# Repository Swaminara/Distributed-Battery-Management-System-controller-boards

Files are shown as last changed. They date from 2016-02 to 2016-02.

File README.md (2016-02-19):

# Distributed-Battery-Management-System-controller-boards

This repository contains the hardware design files of the cell-level controller boards of a distributed Battery Management System.

The boards are designed using Easily Applicable Graphical Layout Editor (EAGLE) 7.1.0 for Windows. However, they can be viewed and edited using other versions also. 

A journal paper explaining the individual modules of the cell-level controller is under review and will be soon updated to this repository. 

This repository is protected under the MIT license as attached in the repository.

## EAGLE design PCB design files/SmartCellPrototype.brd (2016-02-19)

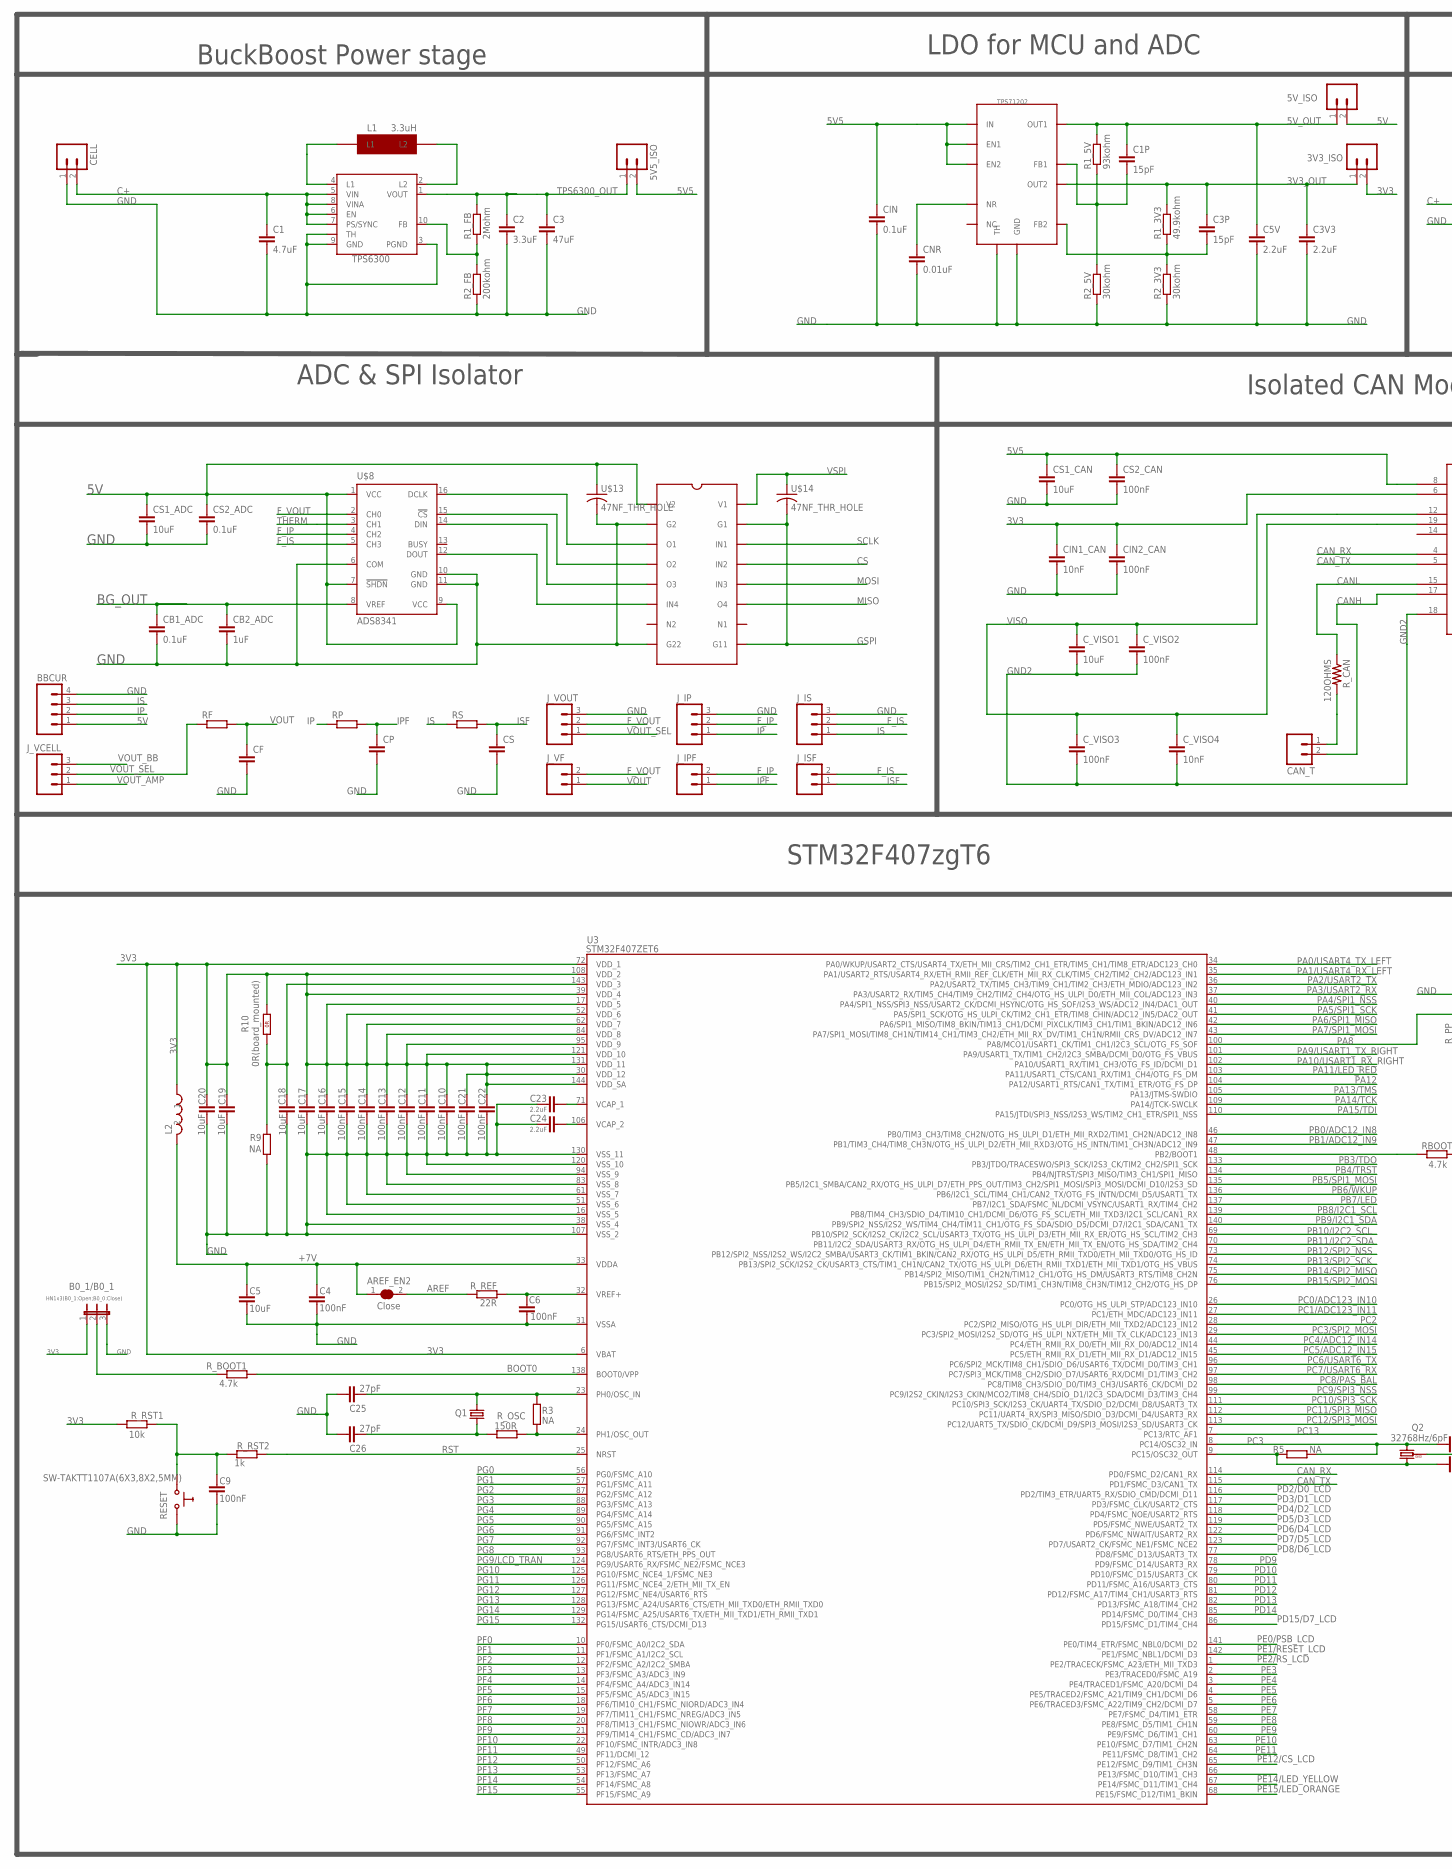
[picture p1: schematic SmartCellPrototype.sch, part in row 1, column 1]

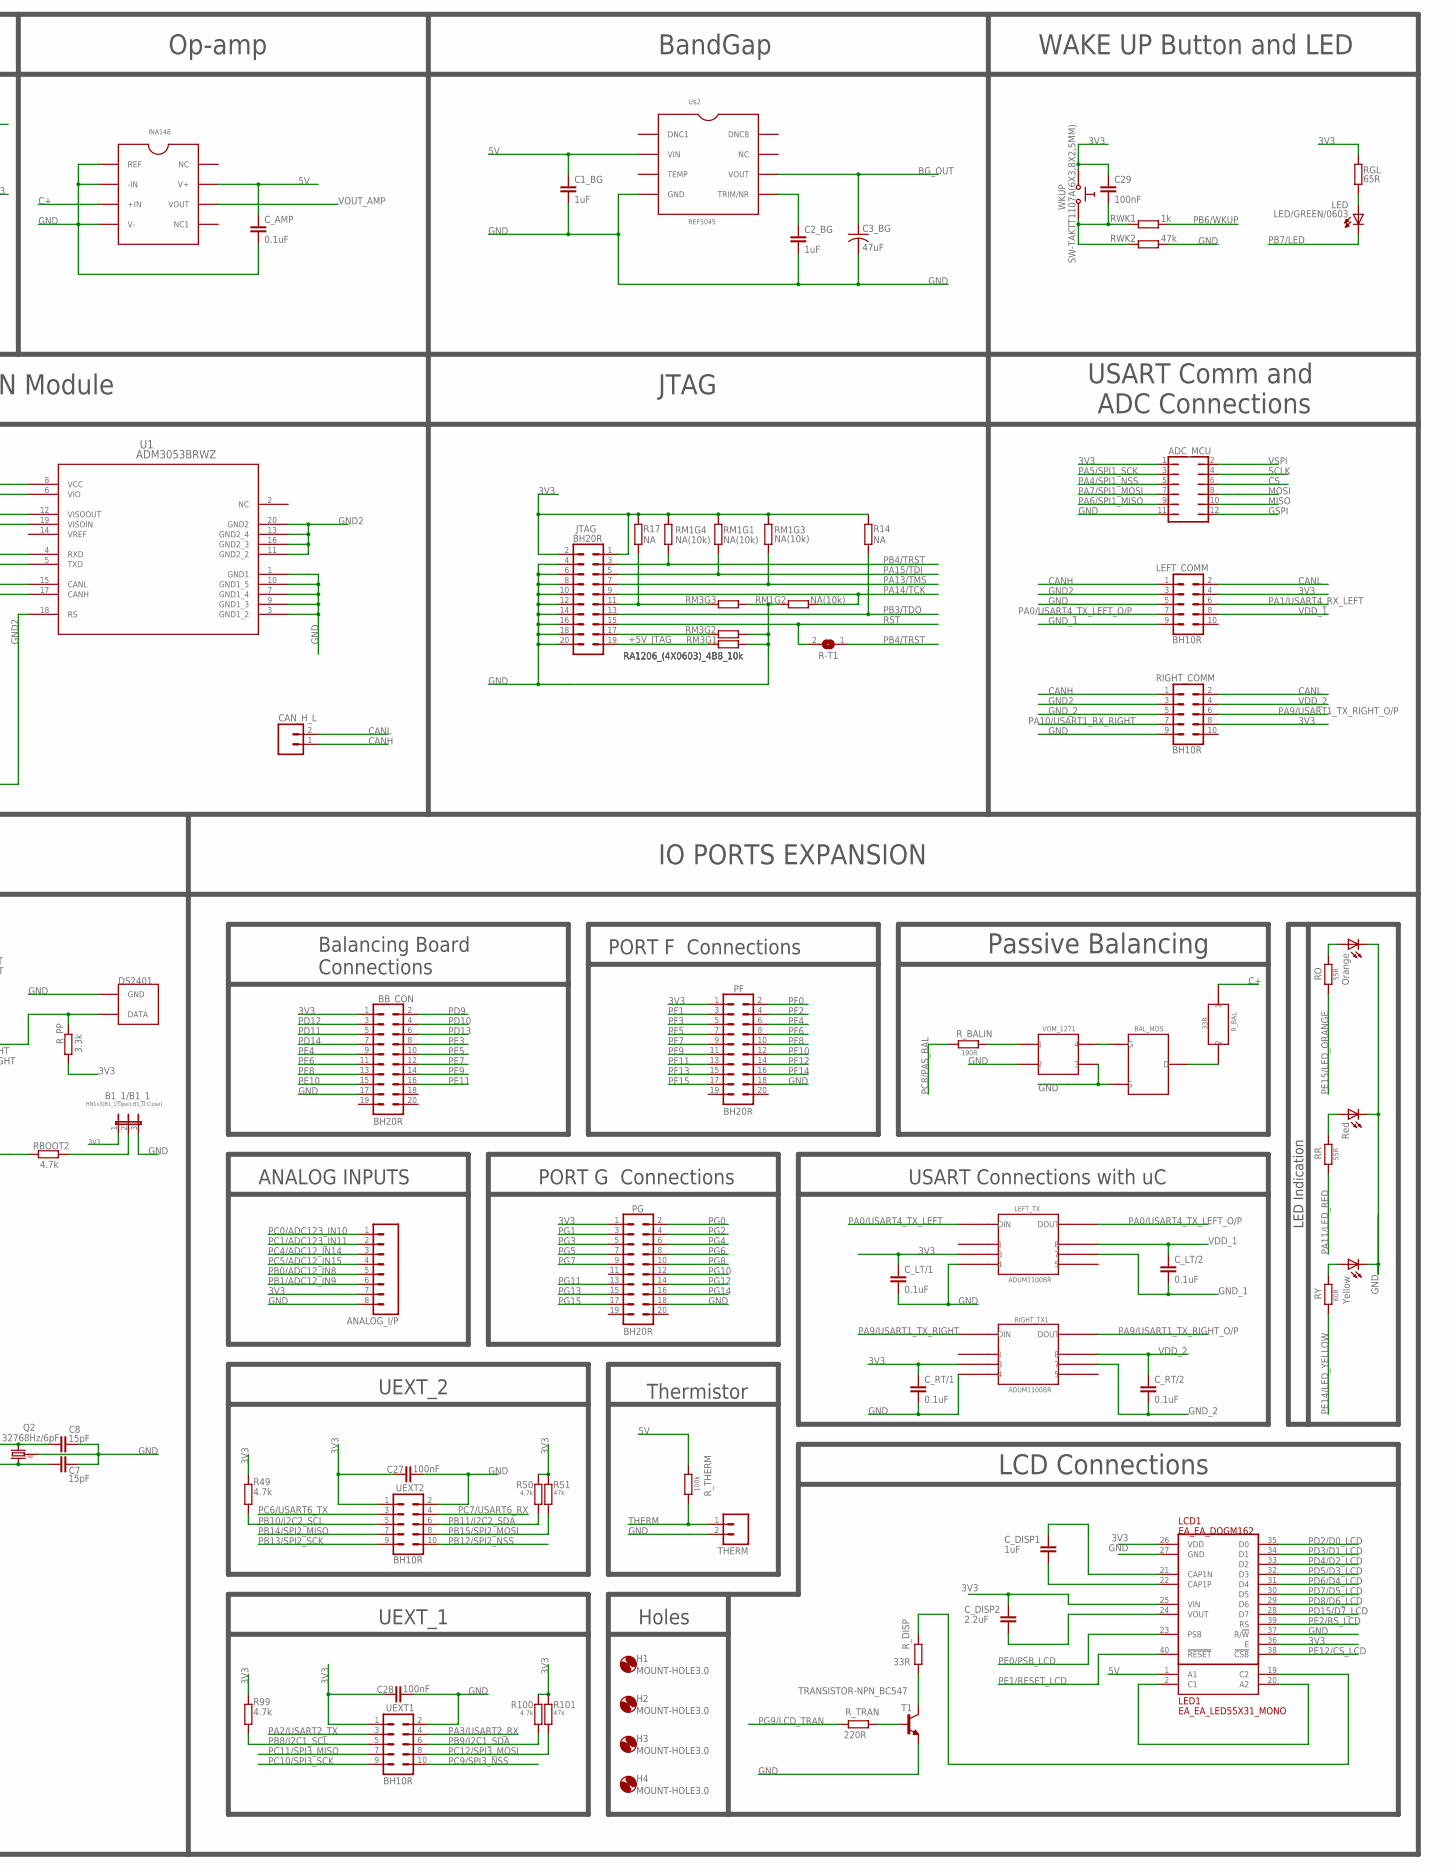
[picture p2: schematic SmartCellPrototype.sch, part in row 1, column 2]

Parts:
3V3_ISO, 5V5_ISO, 5V_ISO: M02PTH; 1X02
ADC_MCU: JP6Q
ANALOG_I/P: M081X08; 1X08
AREF_EN2: Close; SJ_1_SMALLER_CLOSE
B0_1/B0_1: HN1x3(B0_1:Open;B0_0:Close); JP2
B1_1/B1_1: HN1x3(B1_1:Open;B1_0:Close); JP2
BAL_MOS: BAL_MOS
BBCUR: M04PTH; 1X04
BB_CON: BH20R
C1: 4.7uF; C0603
C1P, C3P, C7, C8: 15pF; C0603
C1_BG, C2_BG: 1uF; C0603
C2: 3.3uF; C0603
C3: 47uF; C0805
C3V3, C5V, C23, C24: 2.2uF; C0603
C3_BG: 47uF; C3_BG
C4, C6, C9, C10, C11, C12, C13, C14, C15, C21, C22, C27, C28: 100nF; C0603
C5, C16, C17, C18, C19, C20: 10uF; C0603
C25, C26: 27pF; C0603
C29: 100nF; C0805
CAN_H_L: M02PTH; 1X02
CAN_T: M02PTH; 1X02
CB1_ADC: 0.1uF; C0603
CB2_ADC: 1uF; C0603
CELL: M023.5MM; SCREWTERMINAL-3.5MM-2
CF: C-EUC0603; C0603
CIN: 0.1uF; C0603
CIN1_CAN: 10nF; C0603
CIN2_CAN: 100nF; C0603
CNR: 0.01uF; C0603
CP: C-EUC0603; C0603
CS: C-EUC0603; C0603
CS1_ADC, CS1_CAN: 10uF; C0603
CS2_ADC: 0.1uF; C0603
CS2_CAN: 100nF; C0603
C_AMP: 0.1uF; C0603
C_DISP1: 1uF; C0603
C_DISP2: 2.2uF; C0603
C_LT/1, C_LT/2: 0.1uF; C0603
C_RT/1, C_RT/2: 0.1uF; C0603
C_VISO1: 10uF; C0603
C_VISO2, C_VISO3: 100nF; C0603
C_VISO4: 10nF; C0603
DS2401: DS2401
H1, H2, H3, H4: MOUNT-HOLE3.0; 3,0
HCPL092J-00E: HCPL902
IC1: TPS6300; DRC-S-PVSON-N10
INA148: INA148
JTAG: BH20R
J_IP: M03PTH; 1X03
J_IPF: M02PTH; 1X02
J_IS: M03PTH; 1X03
J_ISF: M02PTH; 1X02
J_VCELL: M03PTH; 1X03
J_VF: M02PTH; 1X02
J_VOUT: M03PTH; 1X03
L1: 3.3uH; IND_COILCRAFT3.3UH
L2: FERRITE_BEAD
LCD1: EA_EA_DOGM162; EA_EA_DOGM
LED: LED/GREEN/0603; LED-0603
LED1: EA_EA_LED55X31_MONO; EA_EA_LED55X31
LEFT_COMM: BH10R
LEFT_TX: ADUM1100BR; R_8
PF: BH20R
PG: BH20R
Q1: HC49/S2; HC49/SMD2
Q2: 32768Hz/6pF; TC26H_3_REPAIR_SMD
R1_3V3: 49.9kohm; R0603
R1_5V: 93kohm; R0603
R1_FB: 2Mohm; R0603
R2_3V3, R2_5V: 30kohm; R0603
R2_FB: 200kohm; R0603
R3, R5, R9, R14, R17: NA; R0603
R10: 0R(board_mounted); 0603_0R
R49, R50, R99, R100: 4.7k; R0603
R51, R101: 47k; R0603
R-T1: Open; SJ_1_SMALLER
RBOOT2: 4.7k; R0603
RESET: SW-TAKTT1107A(6X3,8X2,5MM); WS-TAKT_6X3.5_SMD_NOCREAM
RF: R-EU_R0603; R0603
RGL: 65R; R0603_5MIL_DWS
RIGHT_COMM: BH10R
RIGHT_TX1: ADUM1100BR; R_8
RM1: NA(10k); R_MATRIX_4
RM3: RA1206_(4X0603)_4B8_10k; R_MATRIX_4
RO: 55R; R0603
RP: R-EU_R0603; R0603
RR: 55R; R0603
RS: R-EU_R0603; R0603
RWK1: 1k; R0603_5MIL_DWS
RWK2: 47k; R0603_5MIL_DWS
RY: 60R; R0603
R_BAL: 33R; R_BAL
R_BALIN: 190R; R0603
R_BOOT1: 4.7k; R0603
R_CAN: 120OHMS; 120OHM
R_DISP: 33R; R0603
R_OSC: 150R; R0603
R_PP: 3.3k; R0603
R_REF: 22R; R0603
R_RST1: 10k; R0603
R_RST2: 1k; R0603
R_THERM: 100k; R0603
R_TRAN: 220R; R0603
T1: TRANSISTOR-NPN_BC547; TRANSISTOR-NPN_TO92
THERM: M02JST-PTH-2; JST-2-PTH
U1: ADM3053BRWZ; RW_20
U3: STM32F407ZET6; LQFP144
U$1: TPS71202; TPS71202_LDO_ADC_MCU
U$2: REF5045; REF5045_BG
U$3: Yellow; LED_0805
U$4: Red; LED_0805
U$5: Orange; LED_0805
U$8: ADS8341
U$13, U$14: 47NF_THR_HOLE
UEXT1, UEXT2: BH10R
VOM_1271: VOM1271
WKUP: SW-TAKTT1107A(6X3,8X2,5MM); WS-TAKT_6X3.5_SMD_NOCREAM

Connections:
3V3: 3V3_ISO.2, ADC_MCU.1, ANALOG_I/P.7, B0_1/B0_1.1, B1_1/B1_1.1, BB_CON.1, C10.2, C11.2, C12.2, C13.2, C14.2, C15.2, C16.2, C17.2, C19.2, C20.2, C21.2, C22.2, C27.2, C28.2, C29.2, CIN1_CAN.1, CIN2_CAN.1, C_DISP2.1, C_LT/1.1, C_RT/1.1, JTAG.1, JTAG.2, L2.1, LCD1.25 (VIN), LCD1.26 (VDD), LCD1.36 (E), LEFT_COMM.4, LEFT_TX.3, PF.1, PG.1, R10.2 (1.2), R14.2, R17.2, R49.2, R50.2, R51.2, R99.2, R100.2, R101.2, RGL.2, RIGHT_COMM.8, RIGHT_TX1.3, RM1.1.2 (2), RM1.3.2 (2), RM1.4.2 (2), R_PP.1, R_RST1.2, U1.6 (VIO), U3.6 (VBAT), U3.17 (VDD_5), U3.30 (VDD_12), U3.39 (VDD_4), U3.52 (VDD_6), U3.62 (VDD_7), U3.72 (VDD_1), U3.84 (VDD_8), U3.95 (VDD_9), U3.108 (VDD_2), U3.121 (VDD_10), U3.131 (VDD_11), U3.144 (VDD_SA), UEXT1.1, UEXT2.1, WKUP.P$1 (0)
3V3_OUT: 3V3_ISO.1, C3P.1, C3V3.1, R1_3V3.2, U$1.4 (OUT2)
5V: 5V_ISO.2, BBCUR.1, C1_BG.1, CS1_ADC.1, CS2_ADC.1, C_AMP.1, HCPL092J-00E.V2, INA148.V+, LED1.1 (A1), R_THERM.2, U$2.VIN, U$8.1 (VCC), U$8.7 (!SHDN), U$8.9 (VCC), U$13.1
5V5: 5V5_ISO.2, CIN.1, CS1_CAN.1, CS2_CAN.1, U1.8 (VCC), U$1.1 (IN), U$1.8 (EN2), U$1.10 (EN1)
5V_OUT: 5V_ISO.1, C1P.1, C5V.1, R1_5V.2, U$1.3 (OUT1)
+5V_JTAG: JTAG.19, RM3.1.1 (1)
+7V: AREF_EN2.1, C4.2, C5.1, L2.2, U3.33 (VDDA)
AREF: AREF_EN2.2, R_REF.1
BG_OUT: C3_BG.+, CB1_ADC.1, CB2_ADC.1, U$2.VOUT, U$8.8 (VREF)
BOOT0: R_BOOT1.1, U3.138 (BOOT0/VPP)
C+: C1.1, CELL.2, IC1.5 (VIN), IC1.6 (EN), IC1.7 (PS/SYNC), IC1.8 (VINA), INA148.+IN, R_BAL.1
CANH: CAN_H_L.1, CAN_T.2, LEFT_COMM.1, RIGHT_COMM.1, U1.17 (CANH)
CANL: CAN_H_L.2, LEFT_COMM.2, RIGHT_COMM.2, R_CAN.1, U1.15 (CANL)
CAN_RX: U1.4 (RXD), U3.114 (PD0/FSMC_D2/CAN1_RX)
CAN_TX: U1.5 (TXD), U3.115 (PD1/FSMC_D3/CAN1_TX)
CS: ADC_MCU.6, HCPL092J-00E.IN2
F_IP: J_IP.2, J_IPF.2, U$8.4 (CH2)
F_IS: J_IS.2, J_ISF.2, U$8.5 (CH3)
F_VOUT: J_VF.2, J_VOUT.2, U$8.2 (CH0)
GND: ADC_MCU.11, ANALOG_I/P.8, B0_1/B0_1.3, B1_1/B1_1.3, BAL_MOS.S, BBCUR.4, BB_CON.17, C1.2, C1_BG.2, C2.2, C2_BG.2, C3.2, C3V3.2, C3_BG.-, C4.1, C5.2, C5V.2, C6.1, C7.2, C8.2, C9.1, C10.1, C11.1, C12.1, C13.1, C14.1, C15.1, C16.1, C17.1, C18.1, C19.1, C20.1, C21.1, C22.1, C23.1, C24.1, C25.2, C26.2, C27.1, C28.1, CB1_ADC.2, CB2_ADC.2, CELL.1, CF.2, CIN.2, CIN1_CAN.2, CIN2_CAN.2, CNR.2, CP.2, CS.2, CS1_ADC.2, CS1_CAN.2, CS2_ADC.2, CS2_CAN.2, C_AMP.2, C_LT/1.2, C_RT/1.2, DS2401.GND, HCPL092J-00E.G2, HCPL092J-00E.G22, IC1.3 (PGND), IC1.9 (GND), IC1.TH, INA148.-IN, INA148.REF, INA148.V-, JTAG.4, JTAG.6, JTAG.8, JTAG.10, JTAG.12, JTAG.14, JTAG.16, JTAG.18, JTAG.20, J_IP.3, J_IS.3, J_VOUT.3, LCD1.27 (GND), LCD1.37 (R/!W!), LEFT_COMM.5, LEFT_TX.4, PF.18, PG.18, Q2.GND, R2_3V3.1, R2_5V.1, R2_FB.1, R9.2, RESET.P$2 (1), RIGHT_COMM.9, RIGHT_TX1.4, RM1.2.1 (1), RM3.1.2 (2), RM3.2.2 (2), RM3.3.2 (2), RWK2.1, T1.1 (E), THERM.2, U1.1 (GND1), U1.3 (GND1_2), U1.7 (GND1_4), U1.9 (GND1_3), U1.10 (GND1_5), U3.16 (VSS_5), U3.31 (VSSA), U3.38 (VSS_4), U3.51 (VSS_6), U3.61 (VSS_7), U3.83 (VSS_8), U3.94 (VSS_9), U3.107 (VSS_2), U3.120 (VSS_10), U3.130 (VSS_11), U$1.5 (GND), U$1.TH, U$2.GND, U$3.K (C), U$4.K (C), U$5.K (C), U$8.6 (COM), U$8.10 (GND), U$8.11 (GND), U$13.2, UEXT1.2, UEXT2.2, VOM_1271.2, VOM_1271.3
GND2: C_VISO1.2, C_VISO2.2, C_VISO3.2, C_VISO4.2, LEFT_COMM.3, RIGHT_COMM.3, U1.11 (GND2_2), U1.13 (GND2_4), U1.16 (GND2_3), U1.18 (RS), U1.20 (GND2)
GND_1: C_LT/2.2, LEFT_COMM.9, LEFT_TX.7
GND_2: C_RT/2.2, RIGHT_COMM.5, RIGHT_TX1.7
GSPI: ADC_MCU.12, HCPL092J-00E.G1, HCPL092J-00E.G11, U$14.2
IP: BBCUR.2, J_IP.1, RP.1
IPF: CP.1, J_IPF.1, RP.2
IS: BBCUR.3, J_IS.1, RS.1
ISF: CS.1, J_ISF.1, RS.2
MISO: ADC_MCU.10, HCPL092J-00E.OUT4 (O4)
MOSI: ADC_MCU.8, HCPL092J-00E.IN3
unnamed: IC1.4 (L1), L1.L1
unnamed: IC1.2 (L2), L1.L2
unnamed: CAN_T.1, R_CAN.2
unnamed: C25.1, Q1.1, R3.2, U3.23 (PH0/OSC_IN)
unnamed: IC1.10 (FB), R1_FB.1, R2_FB.2
unnamed: CNR.1, U$1.6 (NR)
unnamed: C3P.2, R1_3V3.1, R2_3V3.2, U$1.7 (FB2)
unnamed: R3.1, R_OSC.2, U3.24 (PH1/OSC_OUT)
unnamed: C2_BG.1, U$2.TRIM/NR
unnamed: C1P.2, R1_5V.1, R2_5V.2, U$1.9 (FB1)
unnamed: B0_1/B0_1.2, R_BOOT1.2
unnamed: C9.2, RESET.P$1 (0), R_RST1.1, R_RST2.2
unnamed: LED.A, RGL.1
unnamed: C26.1, Q1.2, R_OSC.1
unnamed: BAL_MOS.D, R_BAL.2
unnamed: BAL_MOS.G, VOM_1271.4
unnamed: C23.2, U3.71 (VCAP_1)
unnamed: RY.1, U$3.A
unnamed: HCPL092J-00E.IN4, U$8.12 (DOUT)
unnamed: HCPL092J-00E.OUT3 (O3), U$8.14 (DIN)
unnamed: HCPL092J-00E.OUT2 (O2), U$8.15 (!CS)
unnamed: HCPL092J-00E.OUT1 (O1), U$8.16 (DCLK)
unnamed: C_DISP1.1, LCD1.21 (CAP1N)
unnamed: C29.1, RWK1.1, RWK2.2, WKUP.P$2 (1)
unnamed: RR.1, U$4.A
unnamed: RBOOT2.1, U3.48 (PB2/BOOT1)
unnamed: RO.1, U$5.A
unnamed: C24.2, U3.106 (VCAP_2)
unnamed: C_DISP1.2, LCD1.22 (CAP1P)
unnamed: R_BALIN.2, VOM_1271.1
unnamed: C_DISP2.2, LCD1.24 (VOUT)
unnamed: LED1.2 (C1), LED1.20 (A2)
unnamed: C18.2, R9.1, R10.1 (1.1), U3.143 (VDD_3)
unnamed: B1_1/B1_1.2, RBOOT2.2
unnamed: JTAG.11, R17.1, RM3.3.1 (1)
unnamed: JTAG.17, RM3.2.1 (1)
unnamed: LED1.19 (C2), R_DISP.2
unnamed: R_DISP.1, T1.3 (C)
unnamed: R_TRAN.1, T1.2 (B)
PA0/USART4_TX_LEFT: LEFT_TX.2 (DIN), U3.34 (PA0/WKUP/USART2_CTS/USART4_TX/ETH_MII_C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)
PA0/USART4_TX_LEFT_O/P: LEFT_COMM.7, LEFT_TX.6 (DOUT)
PA1/USART4_RX_LEFT: LEFT_COMM.6, U3.35 (PA1/USART2_RTS/USART4_RX/ETH_RMII_REF_C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)
PA2/USART2_TX: U3.36 (PA2/USART2_TX/TIM5_CH3/TIM9_CH1/TIM2_CH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), UEXT1.3
PA3/USART2_RX: U3.37 (PA3/USART2_RX/TIM5_CH4/TIM9_CH2/TIM2_CH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), UEXT1.4
PA4/SPI1_NSS: ADC_MCU.5, U3.40 (PA4/SPI1_NSS/SPI3_NSS/USART2_CK/DCMI_HS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)
PA5/SPI1_SCK: ADC_MCU.3, U3.41 (PA5/SPI1_SCK/OTG_HS_ULPI_CK/TIM2_CH1_ET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)
PA6/SPI1_MISO: ADC_MCU.9, U3.42 (PA6/SPI1_MISO/TIM8_BKIN/TIM13_CH1/DCMI_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)
PA7/SPI1_MOSI: ADC_MCU.7, U3.43 (PA7/SPI1_MOSI/TIM8_CH1N/TIM14_CH1/TIM3_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)
PA8: DS2401.DATA, R_PP.2, U3.100 (PA8/MCO1/USART1_CK/TIM1_CH1/I2C3_SCL/OT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)
PA9/USART1_TX_RIGHT: RIGHT_TX1.2 (DIN), U3.101 (PA9/USART1_TX/TIM1_CH2/I2C3_SMBA/DCMI_D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)
PA9/USART1_TX_RIGHT_O/P: RIGHT_COMM.6, RIGHT_TX1.6 (DOUT)
PA10/USART1_RX_RIGHT: RIGHT_COMM.7, U3.102 (PA10/USART1_RX/TIM1_CH3/OTG_FS_ID/DCMI_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)
PA11/LED_RED: RR.2, U3.103 (PA11/USART1_CTS/CAN1_RX/TIM1_CH4/OTG_FS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)
PA12: U3.104 (PA12/USART1_RTS/CAN1_TX/TIM1_ETR/OTG_FS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)
PA13/TMS: JTAG.7, RM1.3.1 (1), U3.105 (PA13/JTMS-SWDIO)
PA14/TCK: JTAG.9, RM1.2.2 (2), U3.109 (PA14/JTCK-SWCLK)
PA15/TDI: JTAG.5, RM1.1.1 (1), U3.110 (PA15/JTDI/SPI3_NSS/I2S3_WS/TIM2_CH1_ETR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)
PB0/ADC12_IN8: ANALOG_I/P.5, U3.46 (PB0/TIM3_CH3/TIM8_CH2N/OTG_HS_ULPI_D1/E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)
PB1/ADC12_IN9: ANALOG_I/P.6, U3.47 (PB1/TIM3_CH4/TIM8_CH3N/OTG_HS_ULPI_D2/E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)
PB3/TDO: JTAG.13, R14.1, U3.133 (PB3/JTDO/TRACESWO/SPI3_SCK/I2S3_CK/TIM2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)
PB4/TRST: JTAG.3, R-T1.1, RM1.4.1 (1), U3.134 (PB4/NJTRST/SPI3_MISO/TIM3_CH1/SPI1_MISO)
PB5/SPI1_MOSI: U3.135 (PB5/I2C1_SMBA/CAN2_RX/OTG_HS_ULPI_D7/ET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)
PB6/WKUP: RWK1.2, U3.136 (PB6/I2C1_SCL/TIM4_CH1/CAN2_TX/OTG_FS_IN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)
PB7/LED: LED.C, U3.137 (PB7/I2C1_SDA/FSMC_NL/DCMI_VSYNC/USART1_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)
PB8/I2C1_SCL: R99.1, U3.139 (PB8/TIM4_CH3/SDIO_D4/TIM10_CH1/DCMI_D6/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), UEXT1.5
PB9/I2C1_SDA: R100.1, U3.140 (PB9/SPI2_NSS/I2S2_WS/TIM4_CH4/TIM11_CH1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), UEXT1.6
PB10/I2C2_SCL: R49.1, U3.69 (PB10/SPI2_SCK/I2S2_CK/I2C2_SCL/USART3_T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), UEXT2.5
PB11/I2C2_SDA: R50.1, U3.70 (PB11/I2C2_SDA/USART3_RX/OTG_HS_ULPI_D4/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), UEXT2.6
PB12/SPI2_NSS: U3.73 (PB12/SPI2_NSS/I2S2_WS/I2C2_SMBA/USART3_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), UEXT2.10
PB13/SPI2_SCK: U3.74 (PB13/SPI2_SCK/I2S2_CK/USART3_CTS/TIM1_C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), UEXT2.9
PB14/SPI2_MISO: U3.75 (PB14/SPI2_MISO/TIM1_CH2N/TIM12_CH1/OTG_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), UEXT2.7
PB15/SPI2_MOSI: R51.1, U3.76 (PB15/SPI2_MOSI/I2S2_SD/TIM1_CH3N/TIM8_C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), UEXT2.8
PC0/ADC123_IN10: ANALOG_I/P.1, U3.26 (PC0/OTG_HS_ULPI_STP/ADC123_IN10)
PC1/ADC123_IN11: ANALOG_I/P.2, U3.27 (PC1/ETH_MDC/ADC123_IN11)
PC2: U3.28 (PC2/SPI2_MISO/OTG_HS_ULPI_DIR/ETH_MII_T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)
PC3: C8.1, Q2.2, R5.2, U3.8 (PC14/OSC32_IN)
PC3/SPI2_MOSI: U3.29 (PC3/SPI2_MOSI/I2S2_SD/OTG_HS_ULPI_NXT/E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)
PC4: C7.1, Q2.1, R5.1, U3.9 (PC15/OSC32_OUT)
PC4/ADC12_IN14: ANALOG_I/P.3, U3.44 (PC4/ETH_RMII_RX_D0/ETH_MII_RX_D0/ADC12_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)
PC5/ADC12_IN15: ANALOG_I/P.4, U3.45 (PC5/ETH_RMII_RX_D1/ETH_MII_RX_D1/ADC12_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)
PC6/USART6_TX: U3.96 (PC6/SPI2_MCK/TIM8_CH1/SDIO_D6/USART6_TX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), UEXT2.3
PC7/USART6_RX: U3.97 (PC7/SPI3_MCK/TIM8_CH2/SDIO_D7/USART6_RX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), UEXT2.4
PC8/PAS_BAL: R_BALIN.1, U3.98 (PC8/TIM8_CH3/SDIO_D0/TIM3_CH3/USART6_CK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)
PC9/SPI3_NSS: U3.99 (PC9/I2S2_CKIN/I2S3_CKIN/MCO2/TIM8_CH4/S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), UEXT1.10
PC10/SPI3_SCK: U3.111 (PC10/SPI3_SCK/I2S3_CK/UART4_TX/SDIO_D2/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), UEXT1.9
PC11/SPI3_MISO: U3.112 (PC11/UART4_RX/SPI3_MISO/SDIO_D3/DCMI_D4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), UEXT1.7
PC12/SPI3_MOSI: R101.1, U3.113 (PC12/UART5_TX/SDIO_CK/DCMI_D9/SPI3_MOSI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), UEXT1.8
PC13: U3.7 (PC13/RTC_AF1)
PD2/D0_LCD: LCD1.35 (D0), U3.116 (PD2/TIM3_ETR/UART5_RX/SDIO_CMD/DCMI_D11)
PD3/D1_LCD: LCD1.34 (D1), U3.117 (PD3/FSMC_CLK/USART2_CTS)
PD4/D2_LCD: LCD1.33 (D2), U3.118 (PD4/FSMC_NOE/USART2_RTS)
PD5/D3_LCD: LCD1.32 (D3), U3.119 (PD5/FSMC_NWE/USART2_TX)
PD6/D4_LCD: LCD1.31 (D4), U3.122 (PD6/FSMC_NWAIT/USART2_RX)
PD7/D5_LCD: LCD1.30 (D5), U3.123 (PD7/USART2_CK/FSMC_NE1/FSMC_NCE2)
PD8/D6_LCD: LCD1.29 (D6), U3.77 (PD8/FSMC_D13/USART3_TX)
PD9: BB_CON.2, U3.78 (PD9/FSMC_D14/USART3_RX)
PD10: BB_CON.4, U3.79 (PD10/FSMC_D15/USART3_CK)
PD11: BB_CON.5, U3.80 (PD11/FSMC_A16/USART3_CTS)
PD12: BB_CON.3, U3.81 (PD12/FSMC_A17/TIM4_CH1/USART3_RTS)
PD13: BB_CON.6, U3.82 (PD13/FSMC_A18/TIM4_CH2)
PD14: BB_CON.7, U3.85 (PD14/FSMC_D0/TIM4_CH3)
PD15/D7_LCD: LCD1.28 (D7), U3.86 (PD15/FSMC_D1/TIM4_CH4)
PE0/PSB_LCD: LCD1.23 (PSB), U3.141 (PE0/TIM4_ETR/FSMC_NBL0/DCMI_D2)
PE1/RESET_LCD: LCD1.40 (!RESET!), U3.142 (PE1/FSMC_NBL1/DCMI_D3)
PE2/RS_LCD: LCD1.39 (RS), U3.1 (PE2/TRACECK/FSMC_A23/ETH_MII_TXD3)
PE3: BB_CON.8, U3.2 (PE3/TRACED0/FSMC_A19)
PE4: BB_CON.9, U3.3 (PE4/TRACED1/FSMC_A20/DCMI_D4)
PE5: BB_CON.10, U3.4 (PE5/TRACED2/FSMC_A21/TIM9_CH1/DCMI_D6)
PE6: BB_CON.11, U3.5 (PE6/TRACED3/FSMC_A22/TIM9_CH2/DCMI_D7)
PE7: BB_CON.12, U3.58 (PE7/FSMC_D4/TIM1_ETR)
PE8: BB_CON.13, U3.59 (PE8/FSMC_D5/TIM1_CH1N)
PE9: BB_CON.14, U3.60 (PE9/FSMC_D6/TIM1_CH1)
PE10: BB_CON.15, U3.63 (PE10/FSMC_D7/TIM1_CH2N)
PE11: BB_CON.16, U3.64 (PE11/FSMC_D8/TIM1_CH2)
PE12/CS_LCD: LCD1.38 (!CSB!), U3.65 (PE12/FSMC_D9/TIM1_CH3N)
PE14/LED_YELLOW: RY.2, U3.67 (PE14/FSMC_D11/TIM1_CH4)
PE15/LED_ORANGE: RO.2, U3.68 (PE15/FSMC_D12/TIM1_BKIN)
PF0: PF.2, U3.10 (PF0/FSMC_A0/I2C2_SDA)
PF1: PF.3, U3.11 (PF1/FSMC_A1/I2C2_SCL)
PF2: PF.4, U3.12 (PF2/FSMC_A2/I2C2_SMBA)
PF3: PF.5, U3.13 (PF3/FSMC_A3/ADC3_IN9)
PF4: PF.6, U3.14 (PF4/FSMC_A4/ADC3_IN14)
PF5: PF.7, U3.15 (PF5/FSMC_A5/ADC3_IN15)
PF6: PF.8, U3.18 (PF6/TIM10_CH1/FSMC_NIORD/ADC3_IN4)
PF7: PF.9, U3.19 (PF7/TIM11_CH1/FSMC_NREG/ADC3_IN5)
PF8: PF.10, U3.20 (PF8/TIM13_CH1/FSMC_NIOWR/ADC3_IN6)
PF9: PF.11, U3.21 (PF9/TIM14_CH1/FSMC_CD/ADC3_IN7)
PF10: PF.12, U3.22 (PF10/FSMC_INTR/ADC3_IN8)
PF11: PF.13, U3.49 (PF11/DCMI_12)
PF12: PF.14, U3.50 (PF12/FSMC_A6)
PF13: PF.15, U3.53 (PF13/FSMC_A7)
PF14: PF.16, U3.54 (PF14/FSMC_A8)
PF15: PF.17, U3.55 (PF15/FSMC_A9)
PG0: PG.2, U3.56 (PG0/FSMC_A10)
PG1: PG.3, U3.57 (PG1/FSMC_A11)
PG2: PG.4, U3.87 (PG2/FSMC_A12)
PG3: PG.5, U3.88 (PG3/FSMC_A13)
PG4: PG.6, U3.89 (PG4/FSMC_A14)
PG5: PG.7, U3.90 (PG5/FSMC_A15)
PG6: PG.8, U3.91 (PG6/FSMC_INT2)
PG7: PG.9, U3.92 (PG7/FSMC_INT3/USART6_CK)
PG8: PG.10, U3.93 (PG8/USART6_RTS/ETH_PPS_OUT)
PG9/LCD_TRAN: R_TRAN.2, U3.124 (PG9/USART6_RX/FSMC_NE2/FSMC_NCE3)
PG10: PG.12, U3.125 (PG10/FSMC_NCE4_1/FSMC_NE3)
PG11: PG.13, U3.126 (PG11/FSMC_NCE4_2/ETH_MII_TX_EN)
PG12: PG.14, U3.127 (PG12/FSMC_NE4/USART6_RTS)
PG13: PG.15, U3.128 (PG13/FSMC_A24/USART6_CTS/ETH_MII_TXD0/E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)
PG14: PG.16, U3.129 (PG14/FSMC_A25/USART6_TX/ETH_MII_TXD1/ET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)
PG15: PG.17, U3.132 (PG15/USART6_CTS/DCMI_D13)
RST: JTAG.15, R-T1.2, R_RST2.1, U3.25 (NRST)
SCLK: ADC_MCU.4, HCPL092J-00E.IN1
THERM: R_THERM.1, THERM.1, U$8.3 (CH1)
TPS6300_OUT: 5V5_ISO.1, C2.1, C3.1, IC1.1 (VOUT), R1_FB.2
VDD_1: C_LT/2.1, LEFT_COMM.8, LEFT_TX.8
VDD_2: C_RT/2.1, RIGHT_COMM.4, RIGHT_TX1.8
VISO: C_VISO1.1, C_VISO2.1, C_VISO3.1, C_VISO4.1, U1.12 (VISOOUT), U1.19 (VISOIN)
VOUT: CF.1, J_VF.1, RF.2
VOUT_AMP: INA148.VOUT, J_VCELL.1
VOUT_BB: J_VCELL.3
VOUT_SEL: J_VCELL.2, J_VOUT.1, RF.1
VREF+2: C6.2, R_REF.2, U3.32 (VREF+)
VSPI: ADC_MCU.2, HCPL092J-00E.V1, U$14.1

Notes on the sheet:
BuckBoost Power stage
LDO for MCU and ADC
Op-amp
BandGap
ADC & SPI Isolator
Isolated CAN Module
JTAG
IO PORTS EXPANSION
STM32F407zgT6
Balancing Board Connections
PORT F Connections
PORT G Connections
UEXT_2
UEXT_1
ANALOG INPUTS
WAKE UP Button and LED
Passive Balancing
USART Comm and ADC Connections
Thermistor
USART Connections with uC
LED Indication
LCD Connections
Holes

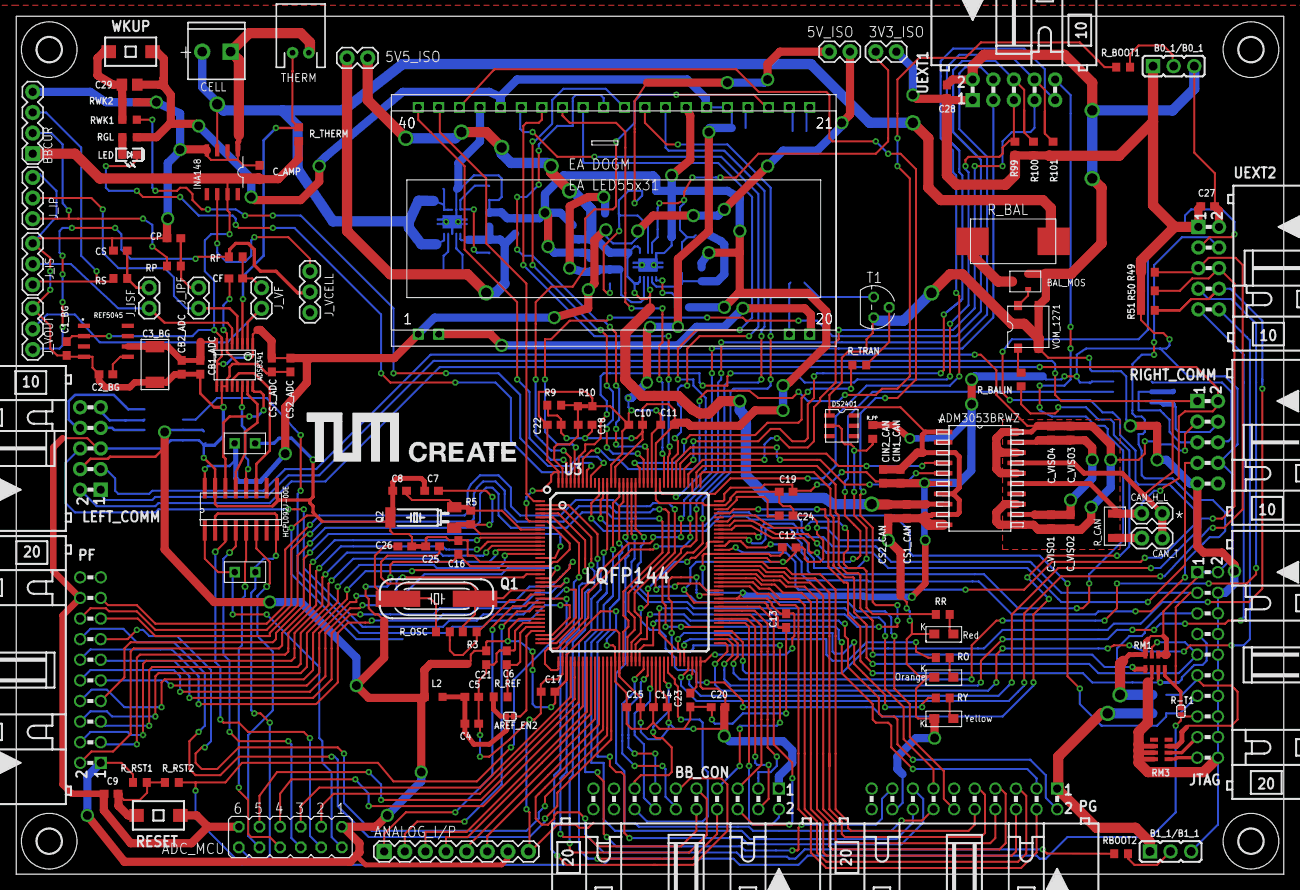
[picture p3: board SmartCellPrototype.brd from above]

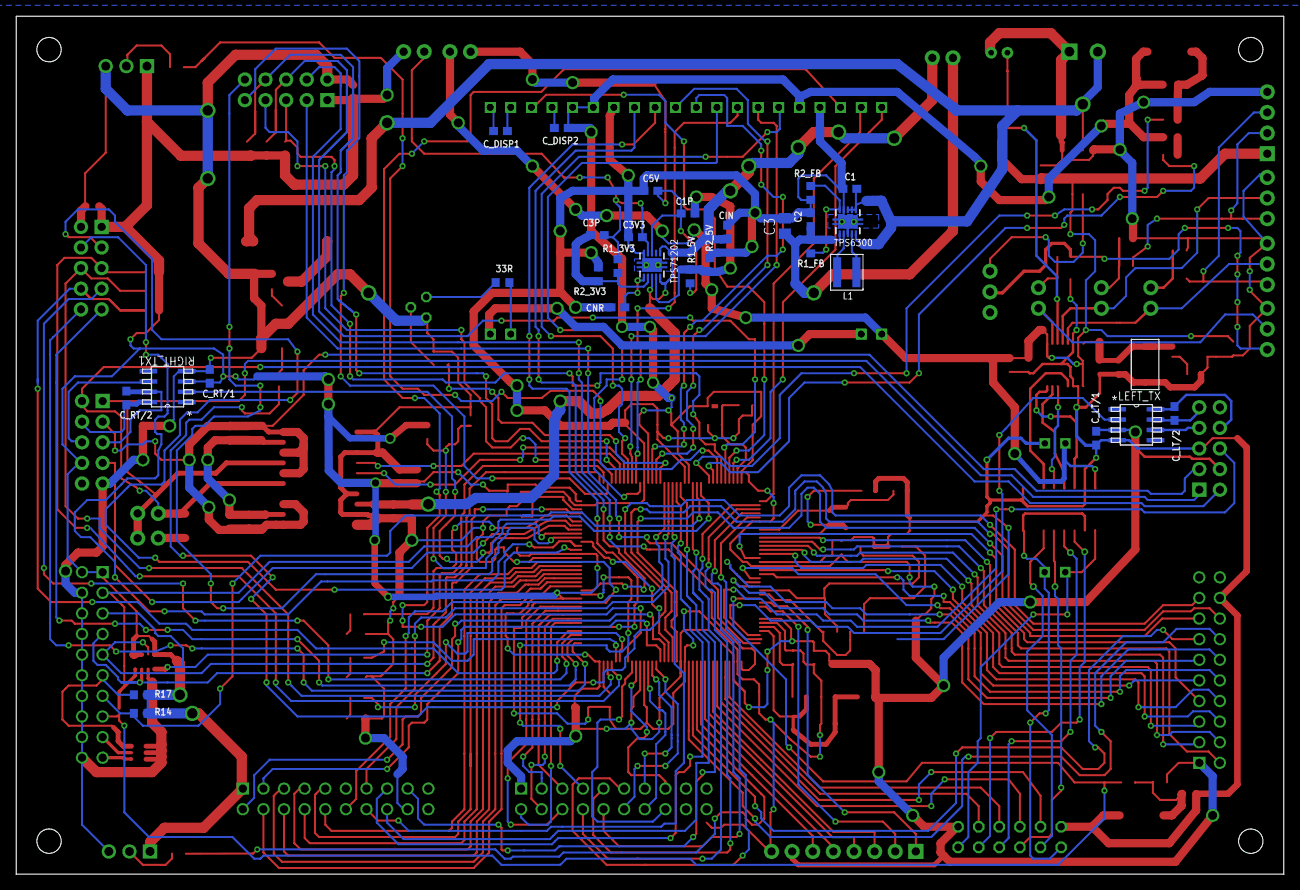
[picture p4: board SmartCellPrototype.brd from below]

Board: 2 copper layers, 156.2 x 105.7 mm, 164 parts (29 on the bottom side), 186 nets.

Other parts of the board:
U$6: BIGGER_LOGO

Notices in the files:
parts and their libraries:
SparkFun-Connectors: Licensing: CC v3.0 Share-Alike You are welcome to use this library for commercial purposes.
